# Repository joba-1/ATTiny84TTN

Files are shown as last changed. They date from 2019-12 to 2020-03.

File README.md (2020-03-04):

# ATTiny84TTN
ATTiny84 TTN Node from Leo Korbee (https://www.iot-lab.org/blog/101/) 
+ optional LED, Serial or Pressure by me (JoBa-1)

## Overview

Send data to TheThingsNetwork. For details look at Leo's great site, in general you need to

* Build breadboard node following Leos cirquit diagram (or use his PCB)
    * ATTiny84 (DIP14 format)
    * RFM95W (solder on an ESP32 breakout board where you removed the 2 10K resistors, not the 0k resistor)
    * BME280 breakout board with 6 pins (4 pins is I2C only, we want SPI)
    * Somewhat optional: 100nF and 470µF condensators at the ATTiny +/Gnd pins
    * You dont need the GPIO outputs from Leos cirquit diagram. They are just nice to have on a PCB
    * Optionally connect a led with 470 Ohm resistor from ground to io pin 1 (PB1).
        * Blinks once at startup (50ms)
        * Blinks fast during startup if BME280 is not found (200ms interval)
        * Blinks short on wakeups (8 s interval)
        * Blinks long on aquiring sensor data and sending to TTN (5 min interval)
    * Optionally connect Gnd and pin 3 (PA7) to an USB2Serial Gnd and Rx to monitor at 9600 baud
        * You cant have serial and lora at the same time though. Not enough flash space :(
* Register a TTN account for free
* Login to TTN
* Go to your account menu (upper left) and select Console
* Create an application: Give it a unique name (ID) and a description. Leave the rest at defaults
* Register your node as a device implementing the application
    * Give it a name and description
    * Select activation method ABP (or adapt the code for OTAA, can be changed later in the TTN device settings)
    * Leave rest at defaults
    * Change device settings: Disable frame checks (since the device resets framecounter on restart)
* Copy file src/secconfig_example.h to src/secconfig.h 
* Copy ID and keys from the device page into the new file (use C-Style)
* Connect the ATTiny84 to your UsbAsp programmer, as usual (or use your own flash method, adapting platformio.ini)
    * you can do these connections on the breadboard, but make sure the programmer only uses 3.3V or your BME280 will not be happy
    * Gnd  <-> Gnd
    * MISO <-> MISO
    * MOSI <-> MOSI
    * SCLK <-> SCLK
    * Reset <-> Reset
    *  +   <-> + (if not powered already)
* Connect the programmer to an USB port
* Call pio run --target upload (or click the right buttons in your IDE of choice...)
* Put the ATTiny in your breadboard, connect power and wait for 8s for the first data to arrive at the TTN device page
    * ...if a gateway is in range
    * ...and you did no mistake - it works for me :P
    
Good Luck
    
## Options

Define your payload format on the TTN application page to use more common units. I use this:

### Decoder
```
function Decoder(bytes, port) {
  var decoded = {};
  
  if (port === 1) {
    decoded.mvcc = bytes[0] | bytes[1] << 8;
    decoded.temp = bytes[2] | bytes[3] << 8 | bytes[4] << 16 | bytes[5] << 24;
    decoded.humi = bytes[6] | bytes[7] << 8 | bytes[8] << 16 | bytes[9] << 24;
    decoded.pres = bytes[10]| bytes[11]<< 8 | bytes[12]<< 16 | bytes[13]<< 24;
  }
  else {
    decoded.humi = -1;
  }

  return decoded;
}
```
### Converter
```
function Converter(decoded, port) {
  var converted = {};

  if (port === 1) {
    converted.vcc_V        = decoded.mvcc / 1000;
    converted.temp_degC    = decoded.temp /  100;
    converted.humi_Percent = decoded.humi / 1000;
    converted.pres_hPa     = decoded.pres /  100;
    if (decoded.humi >= 0 && decoded.humi <= 100000) {
      converted.valid = true;
    }
    else {
      converted.valid = false;
    }
  }

  return converted;
}
```
### Validator
```
function Validator(converted, port) {
  if (port === 1) {
    return converted.valid;
  }
  
  return true;
}
```

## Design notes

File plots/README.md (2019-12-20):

# PLOTS

This describes some bits and pieces to create plots with Grafana dashboards.

## TTN HTTP Integration

The setup is very simple: go to your TTN application (console, Applications, thp84 in my case). 
Select Integrations, add Integration, HTTP Integration.
Use a name meaningful to you as process id (I used thp84-http) and enter the URL you configured your webserver with, e.g. 

    http://your.web.server/ttn/thp84

Select Add integration and you are done.

## Apache configuration

I wont go through apache webserver setup. That is described elsewhere so many times. Just the addons required:

    WSGIScriptAlias /ttn/thp84      /srv/www/htdocs/ttn/thp84.py
    <Directory /srv/www/htdocs/ttn>
      Require all granted
    </Directory>

This configuration file apache2-ttn.conf in /etc/apache2/conf.d/ allows the TTN HTTP integration to post new sensordata to your webserver.
The URL to use is https://your.web.server/ttn/thp84.
But ist should be straightforward to adapt this to your needs now.
You need to install the apache wsgi module for python 3 and enable it.
Obviously you also need Python 3.

    zypper install python3 apache2-mod_wsgi-python3

## Script Installation

Just copy the thp84.py python script to the directory you have configured above (/srv/www/htdocs/ttn).
It will call the InfluxDB url to insert a new measurement via the WSGI interface.
If you use another logfile, InfluxDB server, port or database name, just edit them at the top of the script.

## Manually Insert Measurements

If you want to import the JSON data from your logfile to the InfluxDB database (e.g. to recreate it from scratch)
You can use the same thp84.py script for that:

    cat /var/log/ttn/thp84.log | python3 thp84.py

## InfluxDB and Grafana

Finally you need an InfluxDB database and Grafana.
Again, there are good tutorials out there, I wont repeat. But a general overview I published here:
https://banzhaf.chickenkiller.com/mediawiki/index.php5/Project_TTN_Daten_in_InfluxDB_f%C3%BCr_Grafana

Once you have InfluxDB running, you have to create the database to store the measurements in. Default in the thp84.py script is "ttn".
Create it with this simple command:

    influx -execute 'create database ttn'

As a starting point for Grafana, you can use the JSON file Grafana-dashboard-TTN-thp84-Device.json, which defines a basic dashboard with the collected data

Have fun...
Joachim

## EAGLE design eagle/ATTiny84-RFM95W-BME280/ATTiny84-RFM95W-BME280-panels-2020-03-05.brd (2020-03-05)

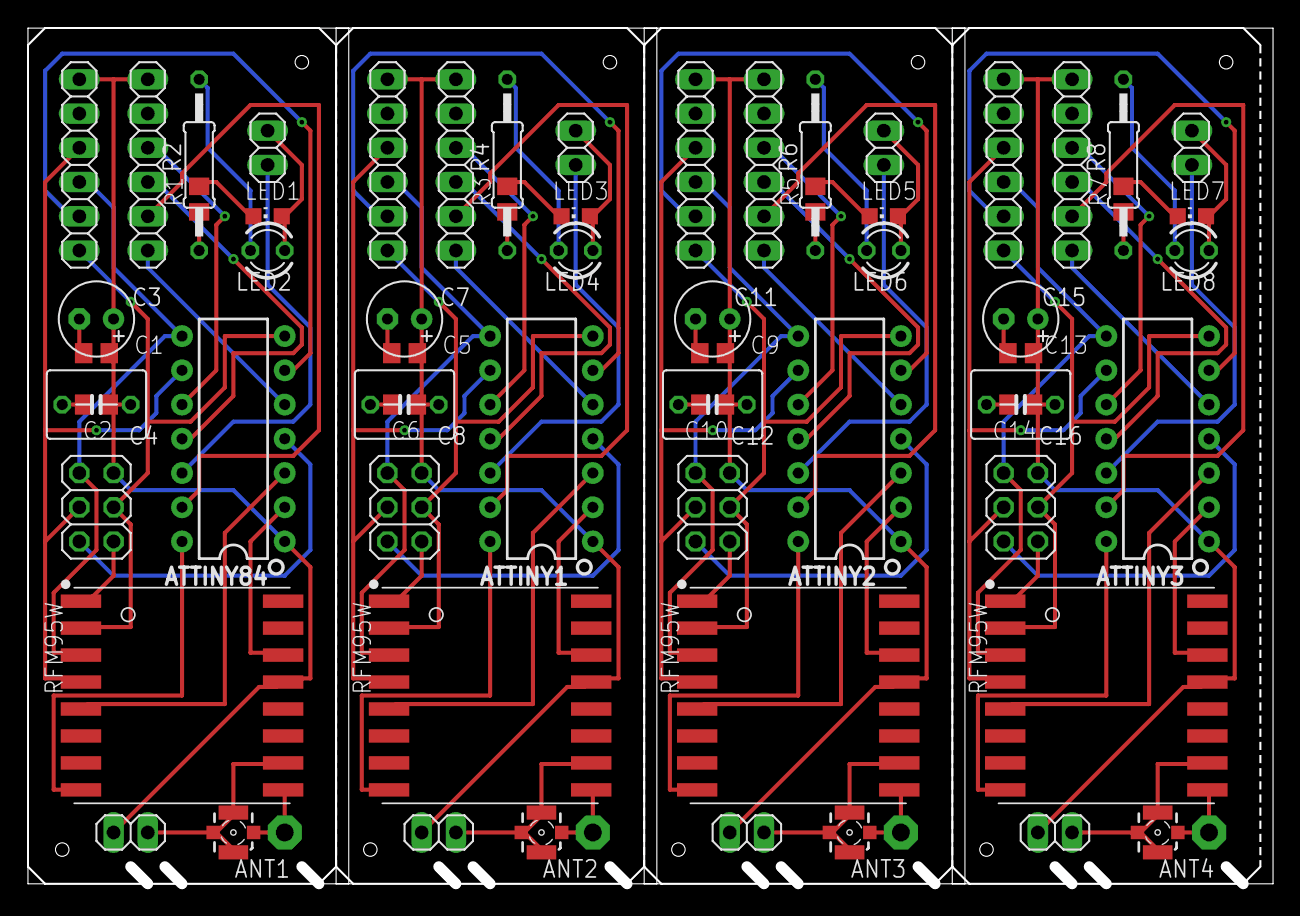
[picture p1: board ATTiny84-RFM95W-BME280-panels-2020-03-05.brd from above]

Board: 2 copper layers, 92.4 x 63.5 mm, 68 parts (0 on the bottom side), 72 nets.

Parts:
ANT1, ANT2, ANT3, ANT4: PAD-01
ATTINY1, ATTINY2, ATTINY3, ATTINY84: ATTINY84ATTINY84-20PU; DIP14
C1, C5, C9, C13: 100µF; C0805
C2, C6, C10, C14: 100nF; C0805
C3, C7, C11, C15: 100µF; E2,5-6
C4, C8, C12, C16: 100nF; C050-050X075
JP1, JP6, JP11, JP16: SPI; 1X06
JP2, JP7, JP12, JP17: LED; 1X02
JP3, JP8, JP13, JP18: GPIO; 1X06
JP4, JP9, JP14, JP19: Power; 1X02
JP5, JP10, JP15, JP20: ISP; 2X03
LED1, LED3, LED5, LED7: CHIP-LED0805
LED2, LED4, LED6, LED8: LED3MM
R1, R3, R5, R7: 470; R0805
R2, R4, R6, R8: 470; 0207/12
RFM95W, RFM95W1, RFM95W2, RFM95W3: RFM95W; RFM95/96/97/98W
X1, X2, X3, X4: 734120110

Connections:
CSB: ATTINY84.6, JP1.5
CSB1: ATTINY1.6, JP6.5
CSB2: ATTINY2.6, JP11.5
CSB3: ATTINY3.6, JP16.5
CSH: ATTINY84.3, RFM95W.NSS
CSH1: ATTINY1.3, RFM95W1.NSS
CSH2: ATTINY2.3, RFM95W2.NSS
CSH3: ATTINY3.3, RFM95W3.NSS
DIO: ATTINY84.2, RFM95W.DIO0
DIO1: ATTINY1.2, RFM95W1.DIO0
DIO2: ATTINY2.2, RFM95W2.DIO0
DIO3: ATTINY3.2, RFM95W3.DIO0
GND: ATTINY84.14, C1.2, C2.2, C3.-, C4.2, JP1.2, JP3.2, JP4.2, JP5.6, R1.1, R2.1, RFM95W.GND@1, RFM95W.GND@2, RFM95W.GND@3, X1.S@1, X1.S@2, X1.S@3
GND1: ATTINY1.14, C5.2, C6.2, C7.-, C8.2, JP6.2, JP8.2, JP9.2, JP10.6, R3.1, R4.1, RFM95W1.GND@1, RFM95W1.GND@2, RFM95W1.GND@3, X2.S@1, X2.S@2, X2.S@3
GND2: ATTINY2.14, C9.2, C10.2, C11.-, C12.2, JP11.2, JP13.2, JP14.2, JP15.6, R5.1, R6.1, RFM95W2.GND@1, RFM95W2.GND@2, RFM95W2.GND@3, X3.S@1, X3.S@2, X3.S@3
GND3: ATTINY3.14, C13.2, C14.2, C15.-, C16.2, JP16.2, JP18.2, JP19.2, JP20.6, R7.1, R8.1, RFM95W3.GND@1, RFM95W3.GND@2, RFM95W3.GND@3, X4.S@1, X4.S@2, X4.S@3
LED: ATTINY84.12, JP2.2
LED1: ATTINY1.12, JP7.2
LED2: ATTINY2.12, JP12.2
LED3: ATTINY3.12, JP17.2
MISO: ATTINY84.7, JP1.6, JP5.4, RFM95W.MISO
MISO1: ATTINY1.7, JP6.6, JP10.4, RFM95W1.MISO
MISO2: ATTINY2.7, JP11.6, JP15.4, RFM95W2.MISO
MISO3: ATTINY3.7, JP16.6, JP20.4, RFM95W3.MISO
MOSI: ATTINY84.8, JP1.4, JP5.1, RFM95W.MOSI
MOSI1: ATTINY1.8, JP6.4, JP10.1, RFM95W1.MOSI
MOSI2: ATTINY2.8, JP11.4, JP15.1, RFM95W2.MOSI
MOSI3: ATTINY3.8, JP16.4, JP20.1, RFM95W3.MOSI
unnamed: ANT1.1, RFM95W.ANT, X1.1
unnamed: ANT2.1, RFM95W1.ANT, X2.1
unnamed: LED1.C, R1.2
unnamed: LED2.K, R2.2
unnamed: LED3.C, R3.2
unnamed: LED4.K, R4.2
unnamed: JP2.1, LED1.A, LED2.A
unnamed: JP7.1, LED3.A, LED4.A
unnamed: ANT3.1, RFM95W2.ANT, X3.1
unnamed: LED5.C, R5.2
unnamed: LED6.K, R6.2
unnamed: JP12.1, LED5.A, LED6.A
unnamed: ANT4.1, RFM95W3.ANT, X4.1
unnamed: LED7.C, R7.2
unnamed: LED8.K, R8.2
unnamed: JP17.1, LED7.A, LED8.A
PA0: ATTINY84.13, JP3.5
PA1: ATTINY1.11, JP8.4
PA2: ATTINY84.11, JP3.4
PA3: ATTINY1.13, JP8.5
PA4: ATTINY2.11, JP13.4
PA5: ATTINY2.13, JP13.5
PA6: ATTINY3.11, JP18.4
PA7: ATTINY3.13, JP18.5
PB1: ATTINY1.5, JP8.6
PB2: ATTINY84.5, JP3.6
PB3: ATTINY2.5, JP13.6
PB4: ATTINY3.5, JP18.6
RESET: ATTINY84.4, JP5.5
RESET1: ATTINY1.4, JP10.5
RESET2: ATTINY2.4, JP15.5
RESET3: ATTINY3.4, JP20.5
SCK: ATTINY84.9, JP1.3, JP5.3, RFM95W.SCK
SCK1: ATTINY1.9, JP6.3, JP10.3, RFM95W1.SCK
SCK2: ATTINY2.9, JP11.3, JP15.3, RFM95W2.SCK
SCK3: ATTINY3.9, JP16.3, JP20.3, RFM95W3.SCK
TX: ATTINY84.10, JP3.3
TX1: ATTINY1.10, JP8.3
TX2: ATTINY2.10, JP13.3
TX3: ATTINY3.10, JP18.3
VCC: ATTINY84.1, C1.1, C2.1, C3.+, C4.1, JP1.1, JP3.1, JP4.1, JP5.2, RFM95W.3.3V
VCC1: ATTINY1.1, C5.1, C6.1, C7.+, C8.1, JP6.1, JP8.1, JP9.1, JP10.2, RFM95W1.3.3V
VCC2: ATTINY2.1, C9.1, C10.1, C11.+, C12.1, JP11.1, JP13.1, JP14.1, JP15.2, RFM95W2.3.3V
VCC3: ATTINY3.1, C13.1, C14.1, C15.+, C16.1, JP16.1, JP18.1, JP19.1, JP20.2, RFM95W3.3.3V

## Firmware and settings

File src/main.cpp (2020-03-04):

/*
  main.cpp
  Main code where the control takes place
  @author  Leo Korbee (c), Leo.Korbee@xs4all.nl
  @website iot-lab.org
  @license Attribution-NonCommercial-ShareAlike 4.0 International (CC BY-NC-SA 4.0)
  Thanks to all the folks who contributed beforme me on this code.

  Hardware information at the end of this file.
  @version 2018-03-31

  @version 2018-06-21
  binary was broken on atmelavr platform 1.9.0 (7200 bytes hex file)
  modified platform.ini to force to platform 1.8.0 (7212 bytes hex file)

  @version 2019-12-13
  * @author Joachim Banzhaf (joachim.banzhaf@gmail.com)
  * optional led indicator
  * optional serial debug output
  * avoid floats by using original bosch driver
  * add pressure to transmitted data
  * send data as 16bit milliVolts and 32bit centiCelsius, milliPercent and Pascal
  */

// LED blinks fast on BME detect and slow on wakeup
#define LED 1
// #undef LED

// Serial debug output
#define TX  3
#undef TX

#define LORA
// #undef LORA

#include <Arduino.h>
#include <avr/sleep.h>
#include <avr/wdt.h>
#include "tinySPI.h"
// lowercase is the original Bosch driver...
#include "bme280.h"
#include "LoRaWAN.h"
#include "secconfig.h" // remember to rename secconfig_example.h to secconfig.h and to modify this file


// all functions declared
ISR(WDT_vect);
void readData(bme280_data *data);
uint16_t vccVoltage();
void setUnusedPins();
void goToSleep();
void watchdogSetup();
void user_delay_ms(uint32_t period);
int8_t user_spi_read(uint8_t dev_id, uint8_t reg_addr, uint8_t *reg_data, uint16_t len);
int8_t user_spi_write(uint8_t dev_id, uint8_t reg_addr, uint8_t *reg_data, uint16_t len);


#ifdef TX
#include <SendOnlySoftwareSerial.h>
#define BAUD 9600
SendOnlySoftwareSerial debug(TX);
#endif

#ifdef LORA
// RFM95W
#define DIO0 10
#define NSS  9
RFM95 rfm(DIO0, NSS);

// define LoRaWAN layer
LoRaWAN lora = LoRaWAN(rfm);
#endif

// frame counter for lora
unsigned int Frame_Counter_Tx = 0x0000;

// BME280 SPI Chipselect pin
#define BME_CS 7
// Default : forced mode, standby time = 1000 ms
struct bme280_dev bme;
struct bme280_data bme_comp;

// set sleep time between broadcasts. The processor awakes after 8 seconds deep-sleep_mode,
// increase and checks the counter and sleep again until sleep_total is reached.
// 5min * 60s = 300/8 = 37,5 = 38.
// Clocks seem slow on the ATTiny84. 35 sleep intervals give more like 5:15 min delay already
const int sleep_total = 35; // 7 -> one broadcast every minute (for sporadic tests)

// sleep cycles that will be counted, start with more than sleep_total to start after 8 seconds with first broadcast.
volatile int sleep_count = sleep_total;


// Interface function required for the Bosch driver
void user_delay_ms(uint32_t period) {
  delay(period);
}

// Interface function required for the Bosch driver
int8_t user_spi_read(uint8_t dev_id, uint8_t reg_addr, uint8_t *reg_data, uint16_t len)
{
  digitalWrite(dev_id, LOW);
  SPI.transfer(reg_addr | 0x80);  // msb set -> read
  while( len-- )
    *(reg_data++) = SPI.transfer(0);
  digitalWrite(dev_id, HIGH);
  return 0;
}

// Interface function required for the Bosch driver
int8_t user_spi_write(uint8_t dev_id, uint8_t reg_addr, uint8_t *reg_data, uint16_t len)
{
  digitalWrite(dev_id, LOW);
  SPI.transfer(reg_addr & ~0x80); // msb clear -> write
  while( len-- )
    SPI.transfer(*(reg_data++));
  digitalWrite(dev_id, HIGH);
  return 0;
}


void setup()
{
#ifdef LED
  pinMode(LED, OUTPUT); // LED for testing...
  digitalWrite(LED, HIGH);
  delay(50);
  static uint8_t isOn = true;
#endif

#ifdef TX
  debug.begin(BAUD);
  debug.print("\n\nbme ");
#endif

  // Init SPI for RFM95 and BME280
  SPI.setDataMode(SPI_MODE0);
  SPI.begin();

#ifdef LORA
  //Initialize RFM module
  rfm.init();
  lora.setKeys(NwkSkey, AppSkey, DevAddr);
#endif

  // for BME sensor
  bme.dev_id = BME_CS;
  // bme.intf = BME280_SPI_INTF;
  bme.read = user_spi_read;
  bme.write = user_spi_write;
  bme.delay_ms = user_delay_ms;

  SPI.setDataMode(SPI_MODE0);
  SPI.begin();

  pinMode(bme.dev_id, OUTPUT);
  digitalWrite(bme.dev_id, HIGH);

  while( BME280_OK != bme280_init(&bme) ) {
#ifdef LED
    isOn = !isOn;
    digitalWrite(LED, isOn ? HIGH : LOW);
#endif
#ifdef TX
    debug.print("NO ");
#endif
    delay(200);
  }

#ifdef TX
  debug.print("setup ");
#endif
  /* Recommended mode of operation: Indoor navigation */
  bme.settings.osr_h = BME280_OVERSAMPLING_1X;
  bme.settings.osr_p = BME280_OVERSAMPLING_16X;
  bme.settings.osr_t = BME280_OVERSAMPLING_2X;
  bme.settings.filter = BME280_FILTER_COEFF_16;

  uint8_t settings_sel = BME280_OSR_PRESS_SEL | BME280_OSR_TEMP_SEL | BME280_OSR_HUM_SEL | BME280_FILTER_SEL;

  if( BME280_OK != bme280_set_sensor_settings(settings_sel, &bme) ) {
#ifdef TX
    debug.print("FAILED! ");
#endif
  }

#ifdef LED
  digitalWrite(LED, LOW);
  delay(200);
#endif
}


#ifdef TX
void printSInt( const char *label, int32_t value ) {
  debug.print(label);
  debug.print("=");
  debug.print(value);
  debug.print(", ");
}


void printUInt( const char *label, uint32_t value ) {
  debug.print(label);
  debug.print("=");
  debug.print(value);
  debug.print(", ");
}
#endif


uint8_t *serialize( uint8_t *data, uint32_t value, size_t size ) {
  while( size-- ) {
    *(data++) = value & 0xff; 
    value >>= 8;
  }
  return data;
}


void loop()
{
  // goToSleep for all devices...
  // The watchdog timer will reset.
#ifdef TX
  debug.println("sleep");
#endif
#ifdef LED
  digitalWrite(LED, LOW);  // LED off while sleeping
#endif
  goToSleep();
#ifdef LED
  digitalWrite(LED, HIGH); // LED on while active
  delay(10);               // make LED blink long enough to be visible
#endif
#ifdef TX
  printUInt("awake", sleep_count);
#endif

  // use this for non-sleep testing:
  //delay(8000);
  //sleep_count++;

  // do action if sleep_total is reached
  if( sleep_count >= sleep_total )
  {
    uint16_t mvcc;

    // define bytebuffer
    uint8_t Data[sizeof(bme_comp) + sizeof(mvcc)];
    uint8_t *data = Data;

    // read data from sensor
    readData(&bme_comp);
    // read vcc voltage (mv)
    mvcc = vccVoltage();

    data = serialize(data, mvcc, sizeof(mvcc));
    data = serialize(data, (uint32_t)bme_comp.temperature, sizeof(bme_comp.temperature));
    data = serialize(data, bme_comp.humidity, sizeof(bme_comp.humidity));
    serialize(data, bme_comp.pressure, sizeof(bme_comp.pressure));

#ifdef TX
    printSInt("Temp", bme_comp.temperature);
    printUInt("Humi", bme_comp.humidity);
    printUInt("Pres", bme_comp.pressure);
    printUInt("mVcc", mvcc);
#endif

#ifdef LORA
    lora.Send_Data(Data, sizeof(Data), Frame_Counter_Tx);
#endif
    Frame_Counter_Tx++;
#ifdef TX
    printUInt("send", Frame_Counter_Tx);
#endif

    // reset sleep count
    sleep_count = 0;
  }
}


/*
  set unused pins so no undefined situation takes place 
  ...and rumor has it this saves power during sleep
*/
void setUnusedPins()
{
  // 0, 1, 2, 3, 8
  pinMode(0, INPUT_PULLUP);
#ifndef LED
  pinMode(1, INPUT_PULLUP);
#endif
  pinMode(2, INPUT_PULLUP);
#ifndef TX
  pinMode(3, INPUT_PULLUP);
#endif
  pinMode(8, INPUT_PULLUP);
}

/**
 read temperature from BME sensor
*/
void readData( bme280_data *data ) {
  if( BME280_OK == bme280_set_sensor_mode(BME280_FORCED_MODE, &bme) ) {
    /* Wait for the measurement to complete */
    bme.delay_ms(40);
    if( BME280_OK != bme280_get_sensor_data(BME280_ALL, data, &bme) ) {
      data->humidity = 0;
      data->pressure = 0;
      data->temperature = 0;
    }
  }
}

/**
  read voltage of the rail (Vcc)
  output mV (2 bytes)
*/
uint16_t vccVoltage()
{
  // Read 1.1V reference against AVcc
  // set the reference to Vcc and the measurement to the internal 1.1V reference
  // default ADMUX REFS1 and REFS0 = 0

  // #define _BV(bit) (1 << (bit))

  // 1.1V (I Ref)(2) 100001
  ADMUX = _BV(MUX5) | _BV(MUX0);

  delay(2); // Wait for Vref to settle
  ADCSRA |= _BV(ADSC); // Start conversion
  while (bit_is_set(ADCSRA,ADSC)); // measuring

  uint8_t low  = ADCL; // must read ADCL first - it then locks ADCH
  uint8_t high = ADCH; // unlocks both

  uint16_t result = (high<<8) | low;

  // result = 1125300L / result; // Calculate Vcc (in mV); 1125300 = 1.1*1023*1000
  // number of steps = 1023??
  result = (1125300L / result) ; // Calculate Vcc (in mV);

  return result;
}


void watchdogSetup()
{
  // Table for clearing/setting bits
  //WDP3 - WDP2 - WPD1 - WDP0 - time
  // 0      0      0      0      16 ms
  // 0      0      0      1      32 ms
  // 0      0      1      0      64 ms
  // 0      0      1      1      0.125 s
  // 0      1      0      0      0.25 s
  // 0      1      0      1      0.5 s
  // 0      1      1      0      1.0 s
  // 0      1      1      1      2.0 s
  // 1      0      0      0      4.0 s
  // 1      0      0      1      8.0 s


  // Reset the watchdog reset flag
  bitClear(MCUSR, WDRF);
  // Start timed sequence
  bitSet(WDTCSR, WDCE); //Watchdog Change Enable to clear WD
  bitSet(WDTCSR, WDE); //Enable WD

  // Set new watchdog timeout value to 8 second
  bitSet(WDTCSR, WDP3);
  bitClear(WDTCSR, WDP2);
  bitClear(WDTCSR, WDP1);
  bitSet(WDTCSR, WDP0);
  // Enable interrupts instead of reset
  bitSet(WDTCSR, WDIE);
}

void goToSleep()
{
  //Disable ADC, saves ~230uA
  ADCSRA &= ~(1<<ADEN);
  watchdogSetup(); //enable watchDog
  set_sleep_mode(SLEEP_MODE_PWR_DOWN);
  // sleep_mode does set and reset the SE bit. sleep_enable and sleep_disable are not usefull
  sleep_mode();
  //disable watchdog after sleep
  wdt_disable();
  // enable ADC
  ADCSRA |=  (1<<ADEN);
}


ISR(WDT_vect)
{
  sleep_count++; // keep track of how many sleep cycles have been completed.
}


/*
  Hardware setup
  Attiny84 using the Arduino pin numbers! PB0 = 0 etc.


  Atmel ATtiny84A PU
  RFM95W
  BME280

  Power: 3V3 - 470uF elco over power connectors, 100nF over power connector for interference suppression
  Connections:
  RFM95W   ATtiny84

  DIO0 -- PB0
  MISO -- MOSI
  MOSI -- MISO
  SCK  -- SCK
  NSS  -- PB1 (this is Chipselect)

  Bosch BME280 sensor used with tinySPI....
  BME280  ATtiny84
  SCL -- SCK
  SDA -- MISO
  SDO -- MOSI
  CSB -- PA7 (this is Chipselect)(Arduino pin 7)
*/

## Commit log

2019-12-10 add serial out and led indicator for debug
2019-12-10 use float for uint64_t to save flash for pressure (not enough...)
2019-12-12 bme now with pressure, no lora but debug output
2019-12-13 make room in ram/flash for sending pressure too
2020-03-04 final version with pressure
2020-03-04 add BME280 driver from Bosch
2020-03-04 save flash and enable led and lora
2020-03-05 add eagle schematics, board and pcb zip
    [ATTiny84-RFM95W-BME280-panels-2020-01-30.brd, ATTiny84-RFM95W-BME280-panels-2020-03-05.brd, ATTiny84-RFM95W-BME280-panels-2020-03-05.sch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]

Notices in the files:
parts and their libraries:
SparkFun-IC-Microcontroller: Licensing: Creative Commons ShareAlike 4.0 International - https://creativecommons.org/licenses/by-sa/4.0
